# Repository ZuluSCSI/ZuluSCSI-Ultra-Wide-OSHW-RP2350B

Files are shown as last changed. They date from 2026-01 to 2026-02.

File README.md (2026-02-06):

ZuluSCSI™ Ultra Wide OSHW - Community Edition - Open Source Hardware
========================
ZuluSCSI Ultra Wide is the worlds first* OSHW _ultra wide_ SCSI emulator. It's an open-source alternative to our commercially-available [ZuluSCSI Wide](https://shop.rabbitholecomputing.com/blogs/news/zuluscsi-wide-33mb-sec-wide-scsi-emulator), which uses much higher-quality printed circuit boards and largely higher-quality components. 

ZuluSCSI Ultra Wide runs unmodified [ZuluSCSI Wide firmware](https://github.com/ZuluSCSI/ZuluSCSI-firmware/releases).

This repository contains the KiCAD 9 schematic and PCB design files for an Open Source Hardware variant of the RP2350B-based ZuluSCSI™ SCSI to SD storage emulator, derived from George Mezzomo's incomplete-at-time-of-forking [RP2350B-based GBSCSI2 wide board](https://github.com/GeorgeRudolf/GBSCSI2/tree/main/rp2350_HD68_3.5). 

Numerous small improvements to routing, pinouts, expansion headers, and power circuitry have been made. As always, firmware for ZuluSCSI is available at http://github.com/ZuluSCSI/ZuluSCSI-firmware

This hardware design is licensed under the terms of the strongly reciprocal CERN OHL-S V2 license, which can be viewed in full at https://ohwr.org/cern_ohl_s_v2.txt and https://ohwr.org/cern_ohl_s_v2.pdf. 

The Rev 2026b ZuluSCSI Ultra Wide OSHW design is [OSHWA-certified](https://certification.oshwa.org/us002798.html)

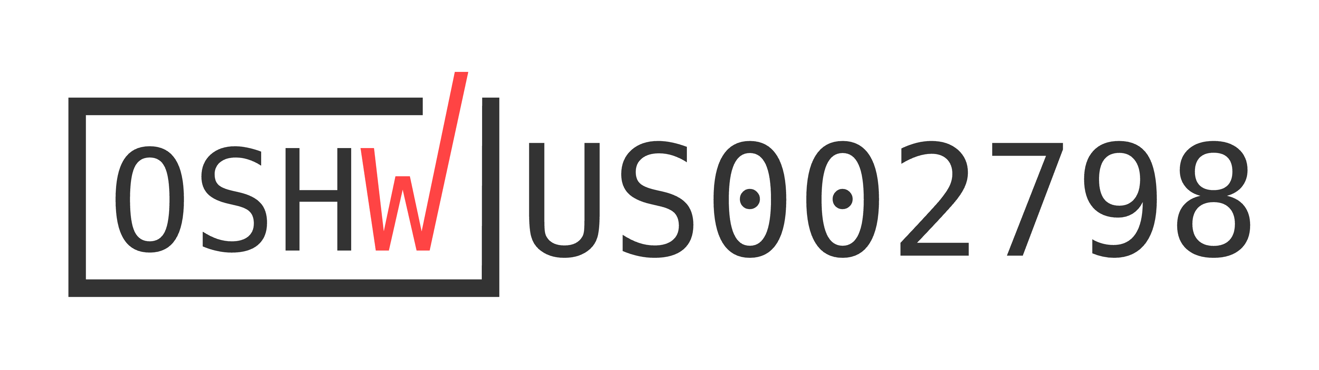
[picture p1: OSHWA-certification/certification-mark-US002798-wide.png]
[](https://certification.oshwa.org/us002798.html)

ZuluSCSI™ is a registered trademark of Rabbit Hole Computing, and may not be used commercially without the express written consent of Rabbit Hole Computing. Individuals producing ZuluSCSI boards for personal use are hereby granted permission to use the ZuluSCSI trademark in a noncommercial capacity.

_Any_ use of the ZuluSCSI trademark in a **commercial** context requires prior written consent from Rabbit Hole Computing.

ZuluSCSI-Ultra-Wide-OSHW-Rev2026b-topDownRender

* that we know of :)

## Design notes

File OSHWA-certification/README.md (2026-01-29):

# ZuluSCSI Ultra Wide OSHWA certification

As of January 28th, 2026, ZuluSCSI Ultra Wide Rev 2026b is [OSHWA-certified](https://certification.oshwa.org/us002798.html)

_Any_ use of the ZuluSCSI trademark in a **commercial** context requires prior written consent from Rabbit Hole Computing.

ZuluSCSI-Ultra-Wide-OSHW-Rev2026b-topDownRender

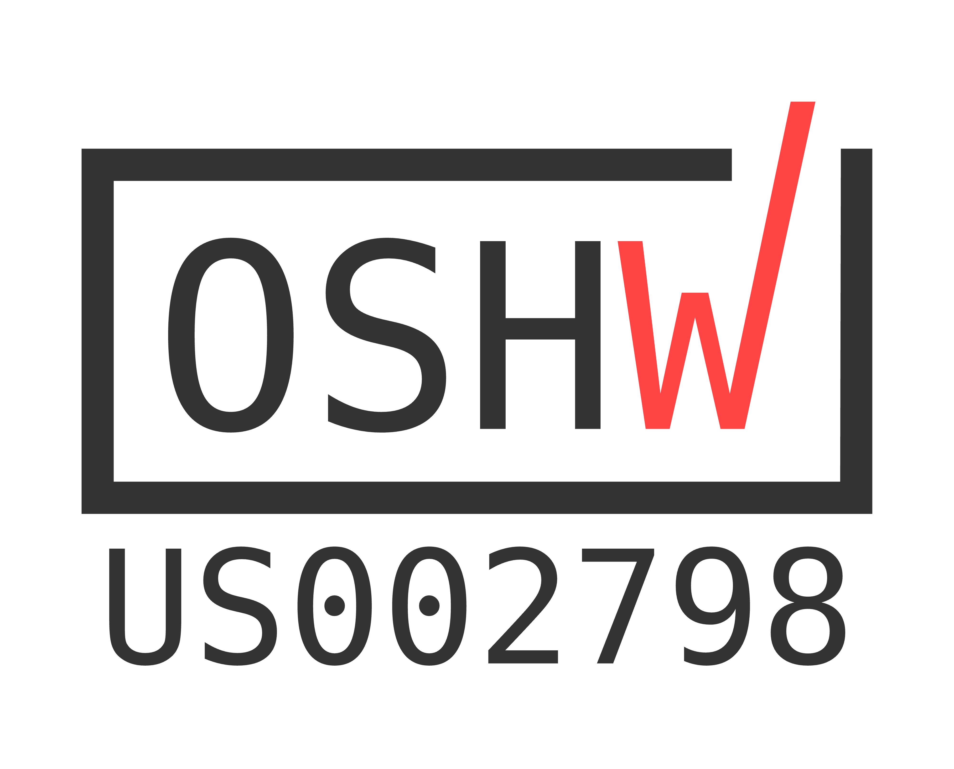
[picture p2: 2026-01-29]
OSHWA-certification/certification-mark-US002798-stacked.png

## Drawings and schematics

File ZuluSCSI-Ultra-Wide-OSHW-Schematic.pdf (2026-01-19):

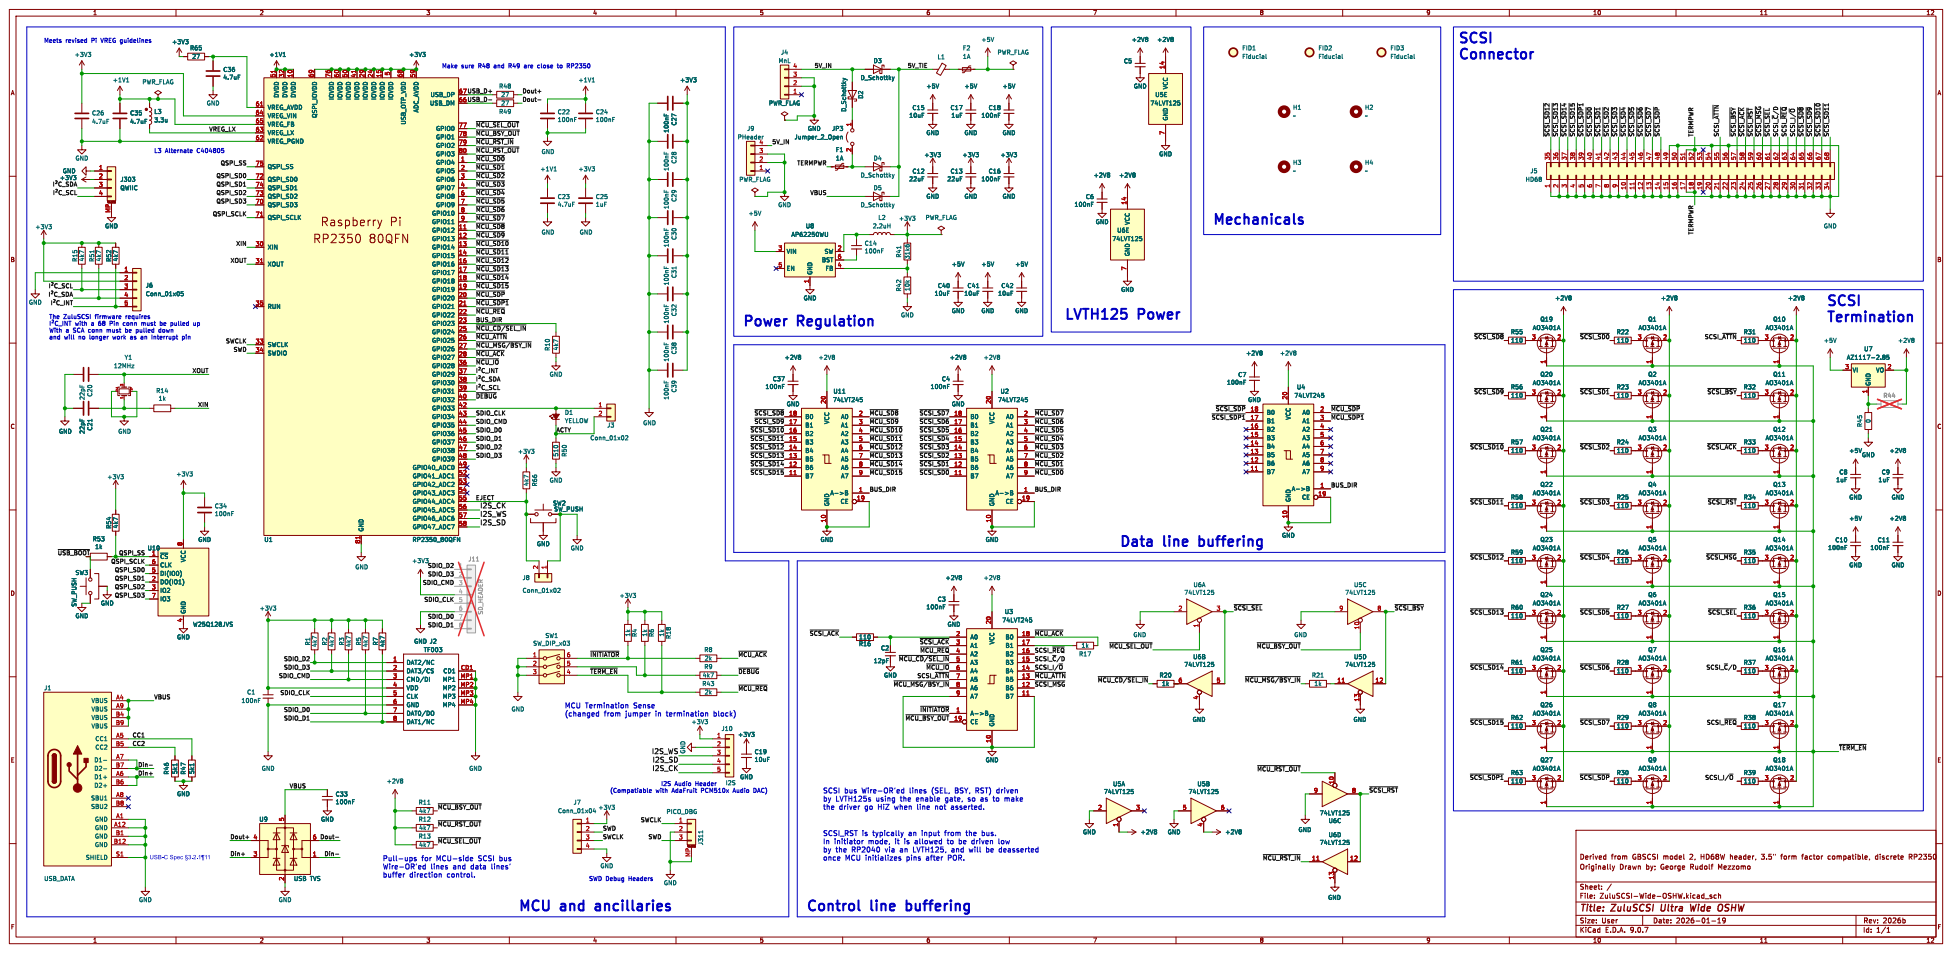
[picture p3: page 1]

Make sure R48 and R49 are close to RP2350 MCU and ancillaries

þÿI²C_INT with a 68 Pin conn must be pulled up With a SCA conn must be pulled down

3 R46 5k1 R47 5k1 GND GND
~{CS} 1 CLK 6 DI(IO0) 5 DO(IO1) 2

4 U10 W25Q128JVS GND GND

by LVTH125s using the enable gate, so as to make
the driver go HiZ when line not asserted.

by the RP2040 via an LVTH125, and will be deasserted

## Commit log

2025-03-10 Initial import of ZuluSCSI Wide OSHW, an RP2350B-based Fast Wide SCSI emulator
    This design is derived from George Mezzomo's RP2350B-based GBSCSI2 wide board, as located at https://github.com/GeorgeRudolf/GBSCSI2/tree/main/rp2350_HD68_3.5
    [ZuluSCSI-Wide-OSHW.kicad_pcb, ZuluSCSI-Wide-OSHW.kicad_sch]
2025-03-10 Switch fonts, modify silkscreen
    [ZuluSCSI-Wide-OSHW.kicad_pcb]
2025-04-14 Update schematic
    [ZuluSCSI-Wide-OSHW.kicad_sch]
2025-06-04 Make board ZuluSCSI firmware compatible
    The initial design of the Wide OSHW had pin differences that were
    incompatible with unmodified ZuluSCSI firmware with wide support.
    The following changes were made:
    - The BUS_DIR changed polarity in the wide firmware thus the A and B
    side on the data buffers had to be swapped
    - 74LVT125 could no longer be used to for the parity pins on the
    data bus. Thus one was replaced with a 74LVT245. Only two of the eight
    bus pins are used on the new 74LVT245. Maybe a different part would
    make sense
    - All the data and control signal buffers have had their VCC changed
    from the 3.3V power to 2.85V power. A section of the 3.3V power
    plane was replace with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
    [ZuluSCSI-Wide-OSHW.kicad_pcb, ZuluSCSI-Wide-OSHW.kicad_sch]
2026-01-10 PCB Update, Layout and DRC passed for rev 2026a
    Schematic updated with more features from the ZuluSCSI wide board.
    JLCPCB parts orientation and position adjusted.
    Silkscreen updated
    Features added:
    - Pico SWD debug header (3 Pin JST header)
    - I2C QWIIC header added (4 pin JST header)
    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
    [ZuluSCSI-Wide-OSHW.kicad_pcb, ZuluSCSI-Wide-OSHW.kicad_sch]
2026-01-19 Improvements to ZuluSCSI Ultra Wide OSHW
    Expanded the description of ZuluSCSI Ultra Wide to include improvements
    and compatibility notes.
    Added CERN Open Hardware Licence Version 2 - Strongly Reciprocal
    (Strict Variant, OHL-S v2) to the project.
    Changes to PCB and Schematic
    - Added missing 3d models of parts
    - Generated 3D step file of the board
    - Printed a PDF of the schematic
    - Standardize footprints & add missing part numbers
    - Add further BOM metadata & lock a few footprints
    - Centered indentation to the SD card
    - Added reference designators and chip type to the buffers
    - Added labels to the external eject and LED headers
    - Added labels on top and bottom for the I2S header
    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
    [ZuluSCSI-Ultra-Wide-OSHW.kicad_sch, ZuluSCSI-Wide-OSHW.kicad_pcb, ZuluSCSI-Wide-OSHW.kicad_sch]
